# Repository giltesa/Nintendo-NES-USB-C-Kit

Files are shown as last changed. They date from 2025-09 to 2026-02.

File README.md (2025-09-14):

# Nintendo NES USB-C Kit

The **Nintendo NES: USB-C Kit** is a board that allows to replace the original charging connector for a modern and standard **USB-C**.

**If your original connector is too old or damaged** and you need a new one, or **if you would like to power up your Super Nintendo with a standard USB-C charger**, such as the charger for your **Nintendo Switch**, phone, or laptop, you can do so with this kit.

Moreover, with this board, **you can remove the original, old, and inefficient power converter**. Since the console operates at 5V, you only need the power from USB-C and a regular charger.

This board is compatible with this model:

*   Nintendo NES

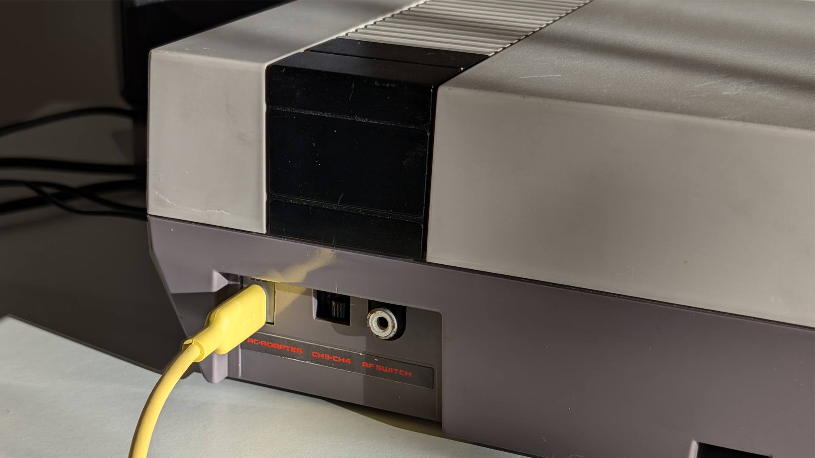
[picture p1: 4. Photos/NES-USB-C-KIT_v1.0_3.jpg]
Nintendo-NES-USB-C


## Would you like it?

https://shop.giltesa.com/product/nintendo-nes-usb-c-kit/

## More

- [giltesa.com](https://giltesa.com "giltesa.com")
- [twitter.com](https://twitter.com/giltesa "twitter.com")

## License

This project is licensed under a **Creative Commons** license:
**[Attribution-NonCommercial-ShareAlike 4.0 International (CC BY-NC-SA 4.0) ](https://creativecommons.org/licenses/by-nc-sa/4.0/)**

Check the [LICENSE.md](LICENSE.md) for more information.

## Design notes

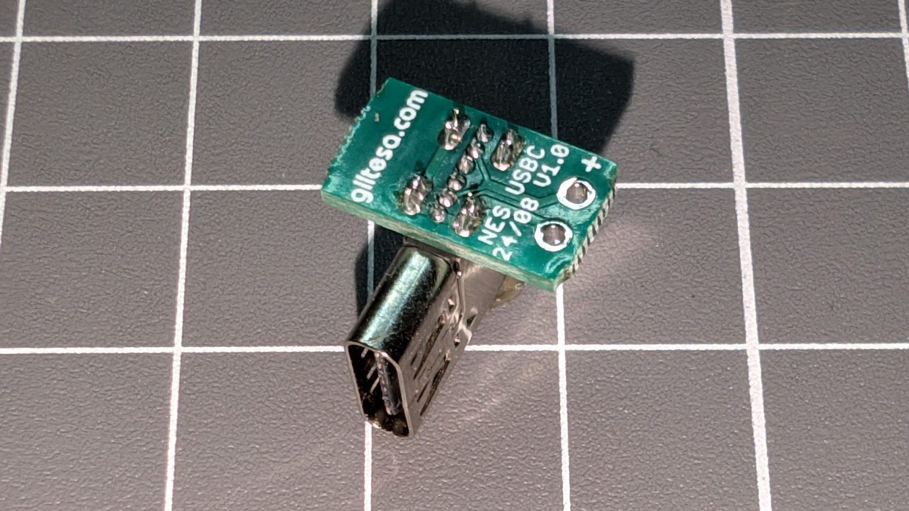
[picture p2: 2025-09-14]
4. Photos/NES-USB-C-KIT_v1.0_1.jpg

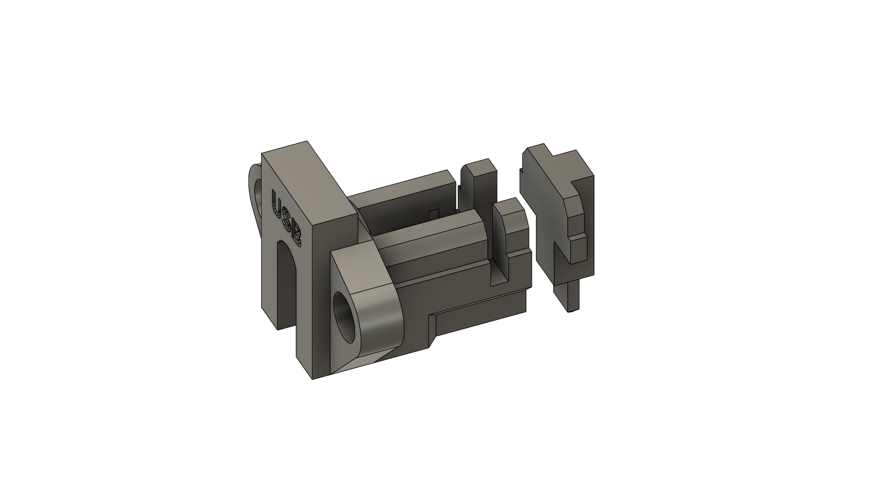
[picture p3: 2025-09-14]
2. Renders, 3D models/Plastic Cap/Nintendo NES Cap v35_2.png

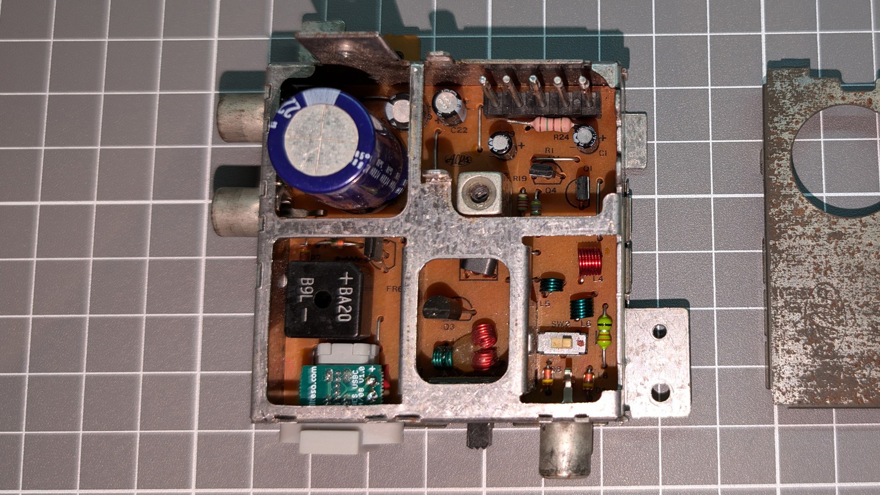
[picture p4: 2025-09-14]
4. Photos/NES-USB-C-KIT_v1.0_2.jpg

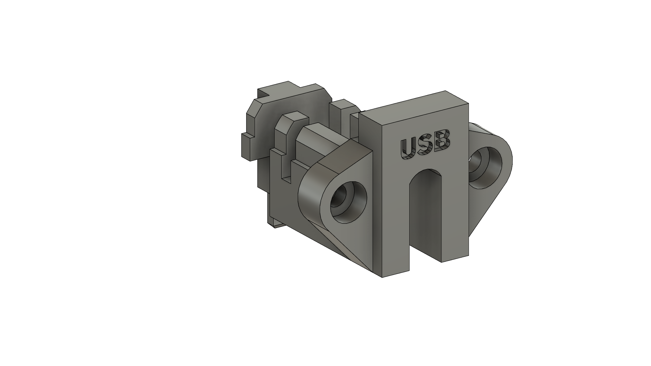
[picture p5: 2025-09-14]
2. Renders, 3D models/Plastic Cap/Nintendo NES Cap v35_1.png

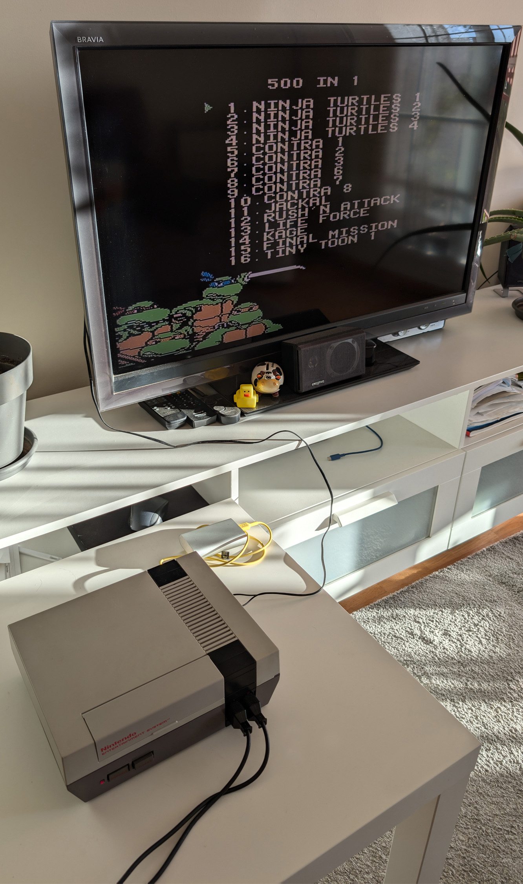
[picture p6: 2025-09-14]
4. Photos/NES-USB-C-KIT_v1.0_4.jpg

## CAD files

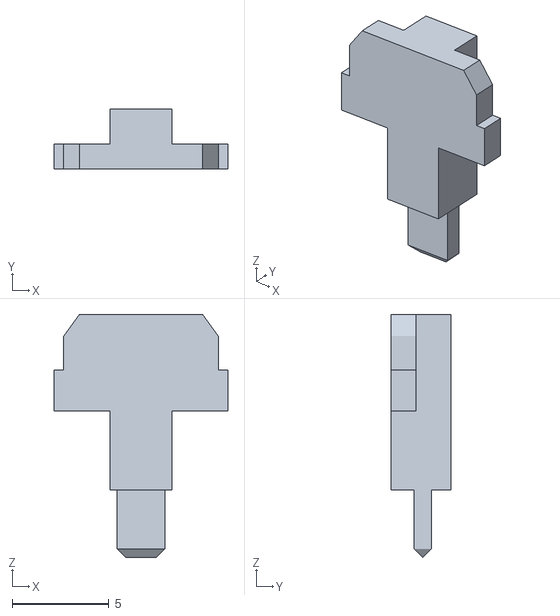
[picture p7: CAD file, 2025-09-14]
2. Renders, 3D models/Plastic Cap/Nintendo NES Cap p2 v35.stl
9.00 x 3.10 x 12.6

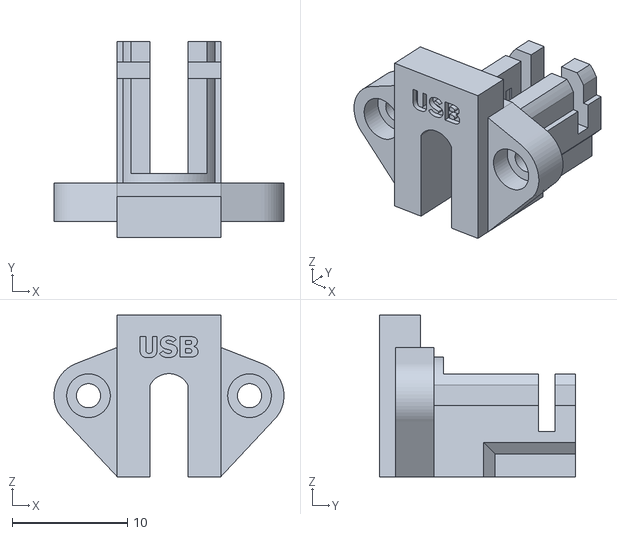
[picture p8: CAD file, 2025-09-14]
2. Renders, 3D models/Plastic Cap/Nintendo NES Cap p1 v35.stl
20.0 x 17.1 x 14.1

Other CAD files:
2. Renders, 3D models/Plastic Cap/Nintendo NES Cap v35.f3d

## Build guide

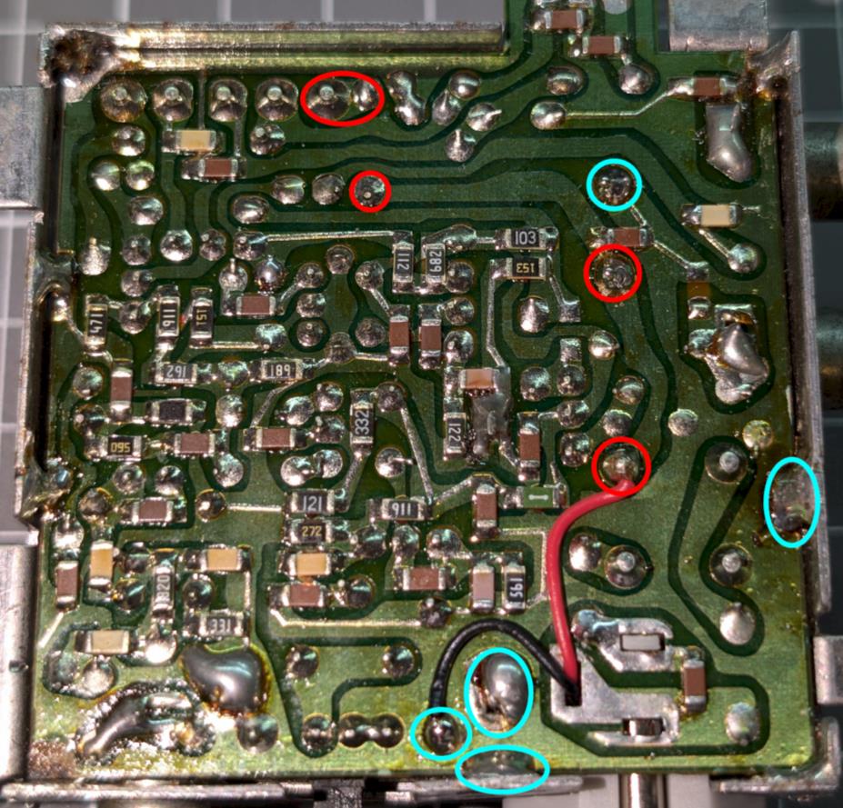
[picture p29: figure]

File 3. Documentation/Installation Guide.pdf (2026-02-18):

# Nintendo NES USB-C Kit

PRODUCT

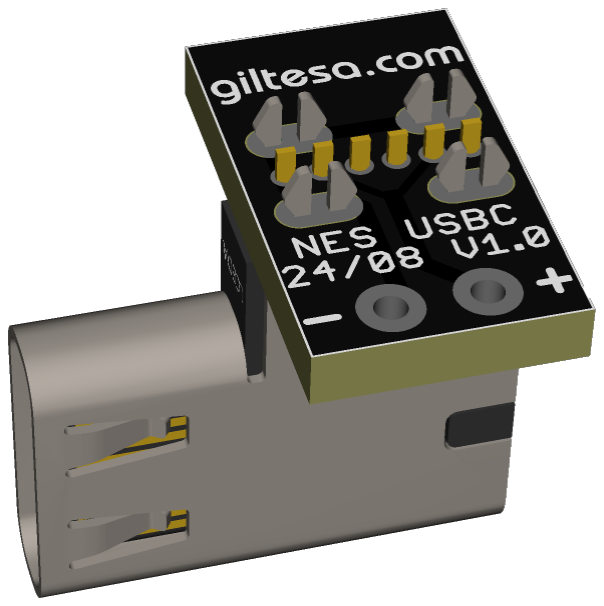
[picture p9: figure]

HTTPS://SHOP.GILTESA.COM/PRODUCT/NINTENDO-NES-USB-C-KIT

# PLEASE READ THROUGH THESE INSTRUCTIONS

ENTIRELY BEFORE ATTEMPTING TO INSTALL.

# WARNING: IF YOU ARE NOT COMFORTABLE WITH SOLDERING, OR PERFORMING ANY STEP IN THIS

GUIDE, DO NOT PERFORM THE INSTALL YOURSELF.

# FIND SOMEONE WHO IS COMFORTABLE TO DO IT FOR

YOU.

INDEX

# Description

The Nintendo NES: USB-C Kit is a board that allows to replace the original power connector for a modern and standard USB-C.

If your original connector is too old or damaged and you need a new one, or if you would like to power up your Nintendo NES with a standard USB-C charger, such as the charger for your Nintendo Switch, phone, or laptop, you can do so with this kit.

Moreover, with this board, you can remove the original, old, and inefficient power converter. Since the console operates at 5V, you only need the power from USB-C and a regular charger.

# FEATURES

- Exact shape for Nintendo NES.
- External power through USB-C.

# INCLUDED

- 1 USB-C board.
- 1 Cable of two wires.
- 1 Plastic cap for the USB-C board.
- 1 Plastic cap retainer.

# Recommended / REQUIRED (NOT INCLUDED)

- Phillips screwdriver.
- Cutting plier.
- Soldering iron / hot-air soldering station.
- Tin.
- Flux.
- Desoldering pump.
- Desoldering mesh.
- Isopropyl alcohol.

# NOTES

This mod disables the video output through the antenna connector, so you will always need to use the AV output.

# Board details

There are 2 pads where the included wires can be soldered. The following explains what each pad is for.

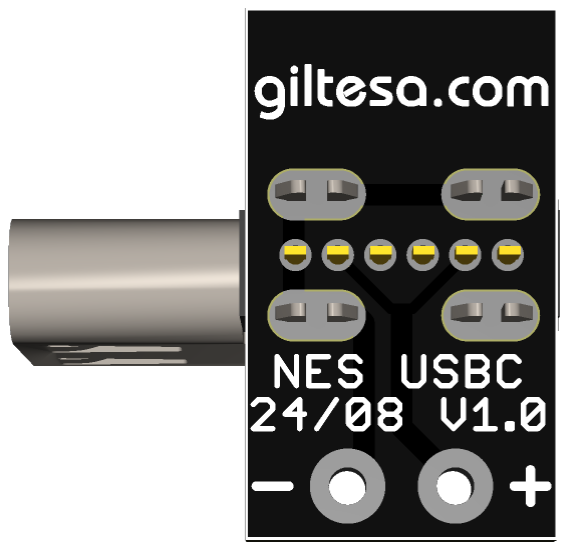
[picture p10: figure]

- + | The +5V line output to power the NES main board.
- - | The ground pad.

# Test the board!

Before starting the installation, you should test the board. If it doesn’t work contact me for a replacement (https://shop.giltesa.com/refund-policy/) (all boards are fully tested, but they may damage during the shipping, we try to package them as better as possible), if it works, go ahead with the installation.

Connect the power from your USB charger to the USB-C connector on the board. Then, with a multimeter in voltage measurement mode, check for a 5V reading. If that's the case, continue with the installation.

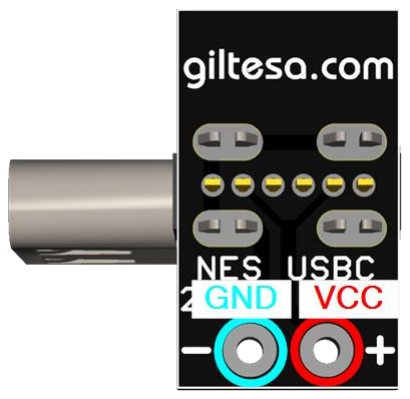
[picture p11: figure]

# INSTALLATION STEPS

Please, carefully read the following steps for a successful installation.

## Pre installation Steps

Before the installation, your NES may need some extra steps to have it ready for the kit.

1. Disassembly the Nintendo NES

Use phillips screwdriver to open the shell and remove the 6 screws.

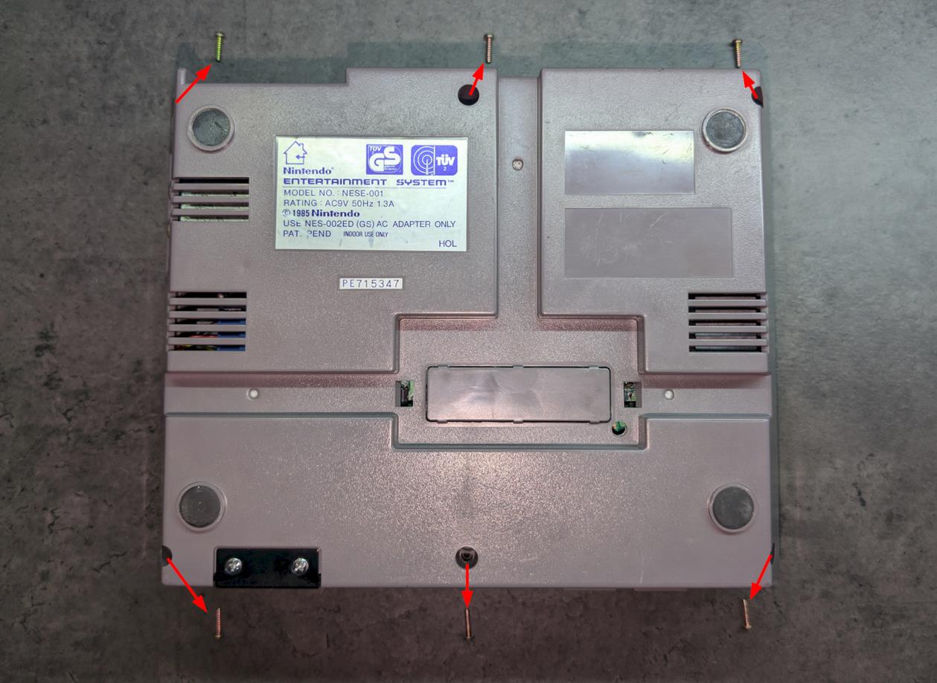
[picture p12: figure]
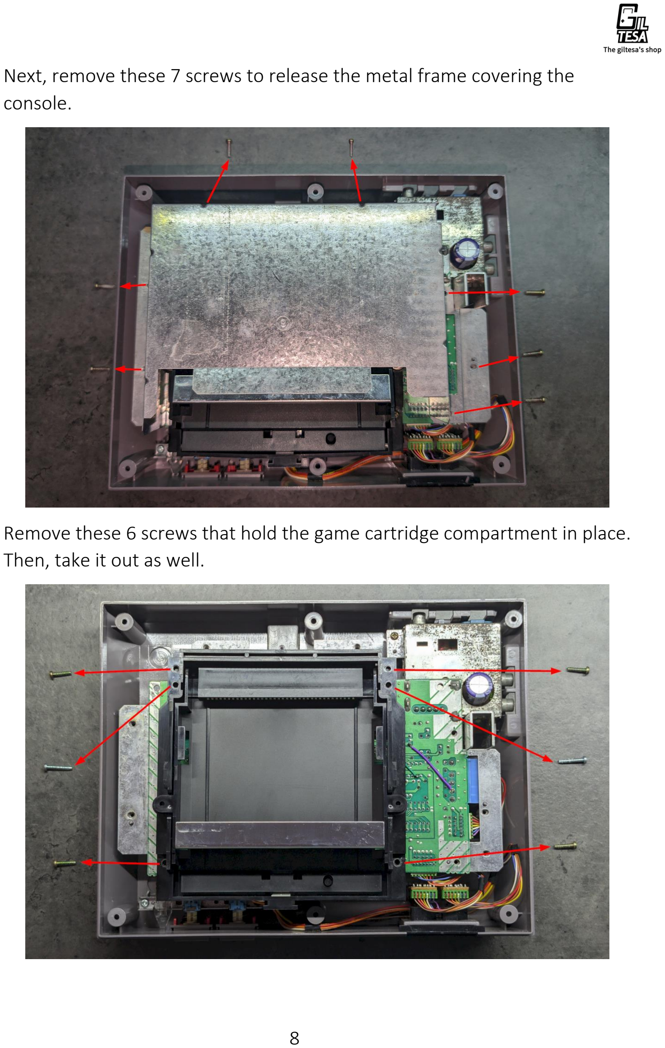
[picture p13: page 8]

Next, remove these 7 screws to release the metal frame covering the console.

Remove these 6 screws that hold the game cartridge compartment in place. Then, take it out as well.

Finally, take out these 2 screws. After that, you can remove the circuit board from the lower shell, but first, disconnect the three cables that connect the circuit board to the shell.

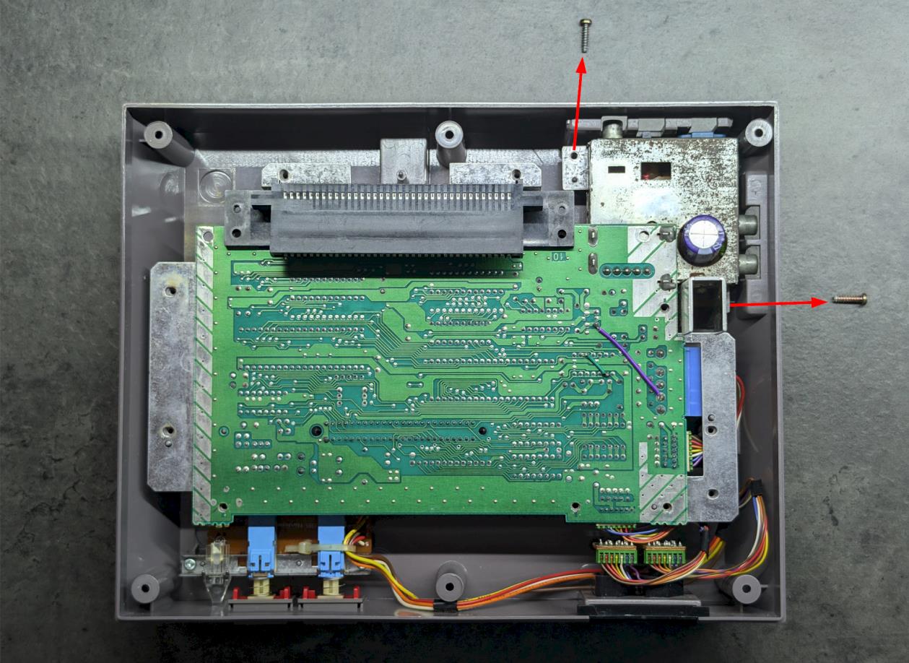
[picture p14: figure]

Now begins the most complex part of the installation. You need to remove the metal box that contains all the power, video, and audio connectors. Inside, you'll find the power connector, which needs to be replaced, along with some small modifications to the circuit.

Desolder all these pads using the soldering iron at maximum power. If you have a hot air soldering station, you can heat the PCB simultaneously to help with the process.

IMPORTANT NOTE: If you use a hot air station, cover the blue capacitor on the right with kapton tape. You should also remove the game connector on the left (it’s not soldered, just slotted in, and can be easily removed and reinserted).

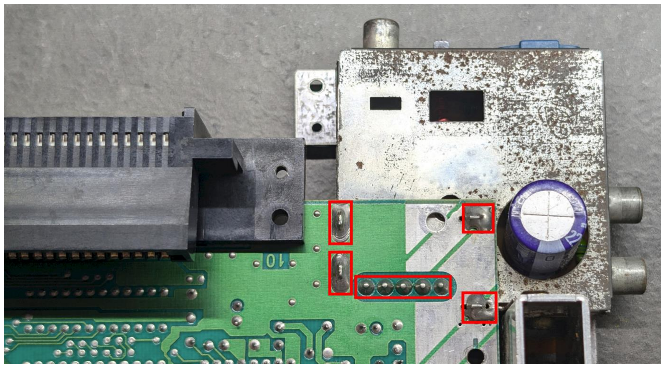
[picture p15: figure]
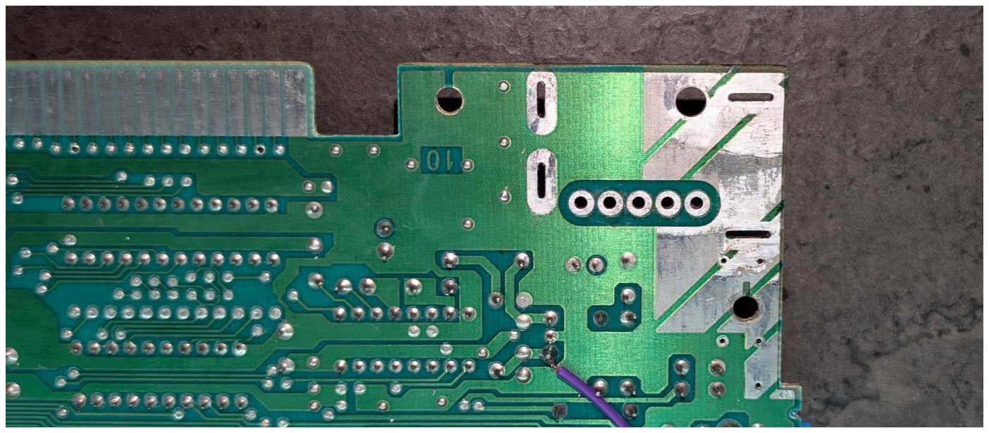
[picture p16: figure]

## installation Steps

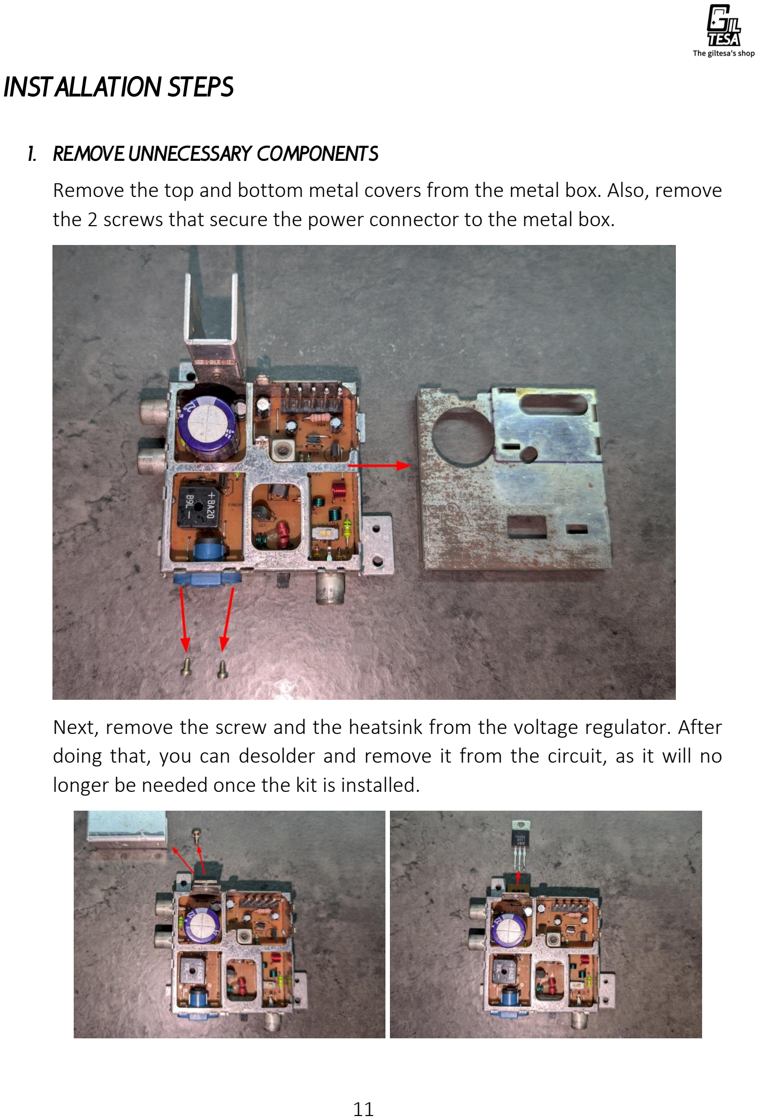
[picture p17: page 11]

1. Remove unnecessary components

Remove the top and bottom metal covers from the metal box. Also, remove the 2 screws that secure the power connector to the metal box.

Next, remove the screw and the heatsink from the voltage regulator. After doing that, you can desolder and remove it from the circuit, as it will no longer be needed once the kit is installed.

It's impossible to remove the power connector without breaking it. This is because the metal shell and the circuit board encase the connector.

The easiest and most recommended way is to destroy the power connector using cutting plier, allowing it to be removed. To do this:

- First, desolder the connector, trying to remove as much solder as possible from its 3 pads.
- Then, use cutting plier to cut it into pieces until it is completely removed.
- Finally, make sure the pads where the connector was soldered are completely free of solder, with the holes fully clear. This is necessary for later steps.

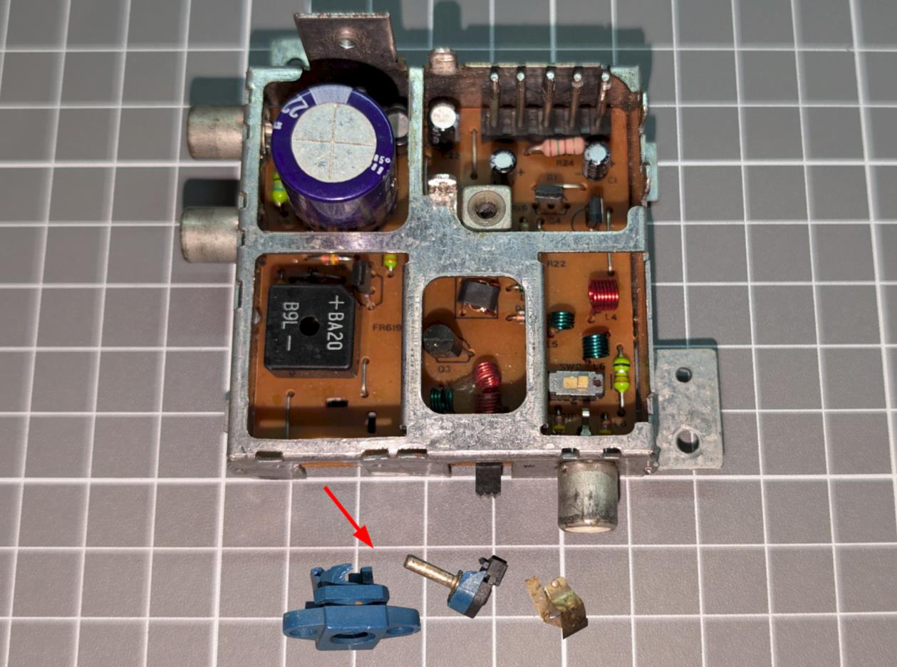
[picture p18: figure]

2. Cable installation

Solder the included wires onto the pads of the USB-C board. Solder the red wire to the pad marked with a +, and the black wire to the pad marked with a –

Clean the circuit with alcohol once you finish soldering the wires.

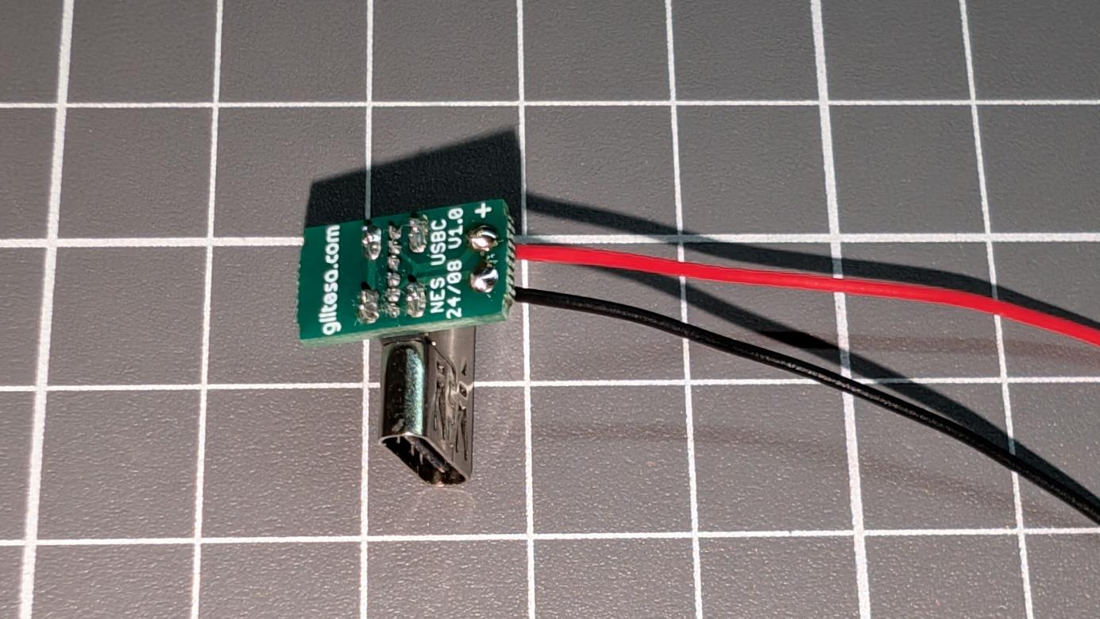
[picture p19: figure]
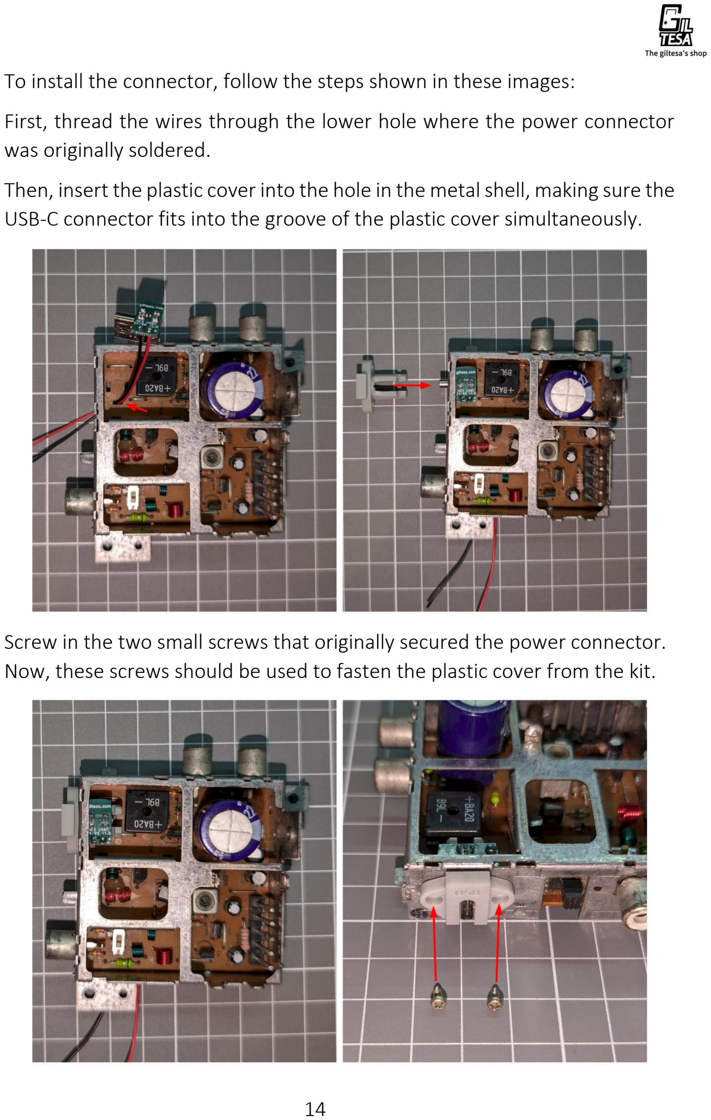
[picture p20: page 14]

To install the connector, follow the steps shown in these images:

First, thread the wires through the lower hole where the power connector was originally soldered.

Then, insert the plastic cover into the hole in the metal shell, making sure the USB-C connector fits into the groove of the plastic cover simultaneously.

Screw in the two small screws that originally secured the power connector. Now, these screws should be used to fasten the plastic cover from the kit.

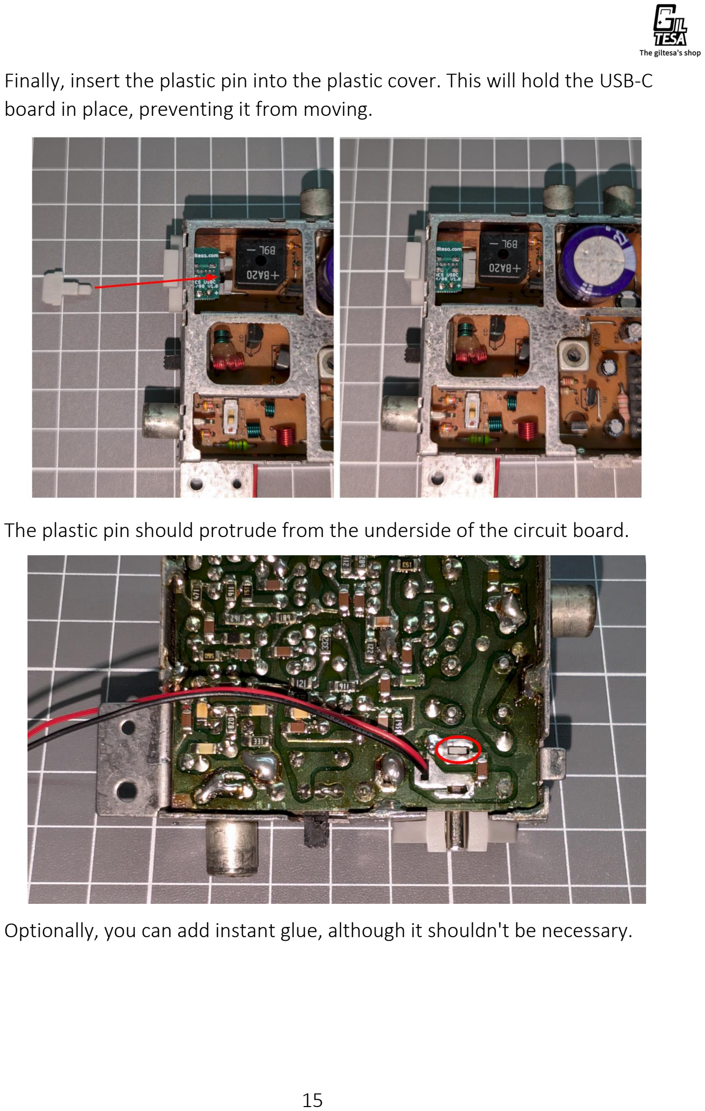
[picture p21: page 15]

Finally, insert the plastic pin into the plastic cover. This will hold the USB-C board in place, preventing it from moving.

The plastic pin should protrude from the underside of the circuit board.

Optionally, you can add instant glue, although it shouldn't be necessary.

Solder the wires onto these two pads, making sure they are cut to the correct length beforehand.

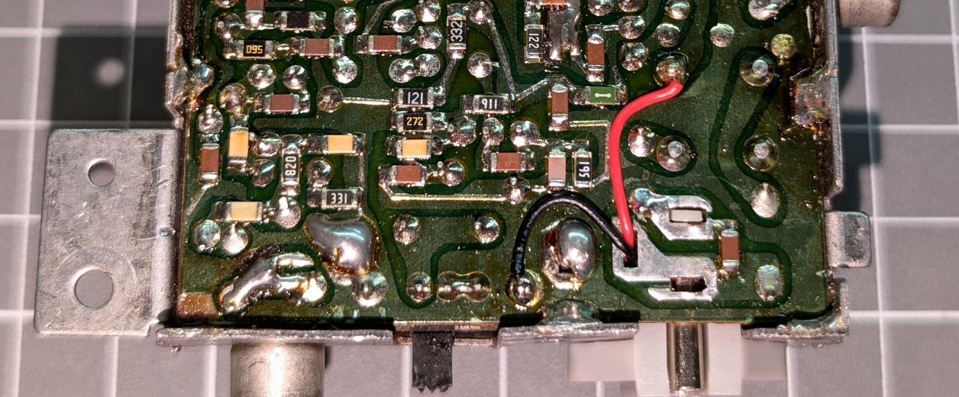
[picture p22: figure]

Since there are different versions of the circuit and the pads may be slightly repositioned, you can ensure that you are soldering each wire to the correct location by using a multimeter.

The black wire (GND) should be soldered to the pad shown in the photo, which is connected to the GND plane of the circuit and the metal shell covering it.

The red wire should be connected to the positive pad of the large capacitor, as well as to the power output pin.

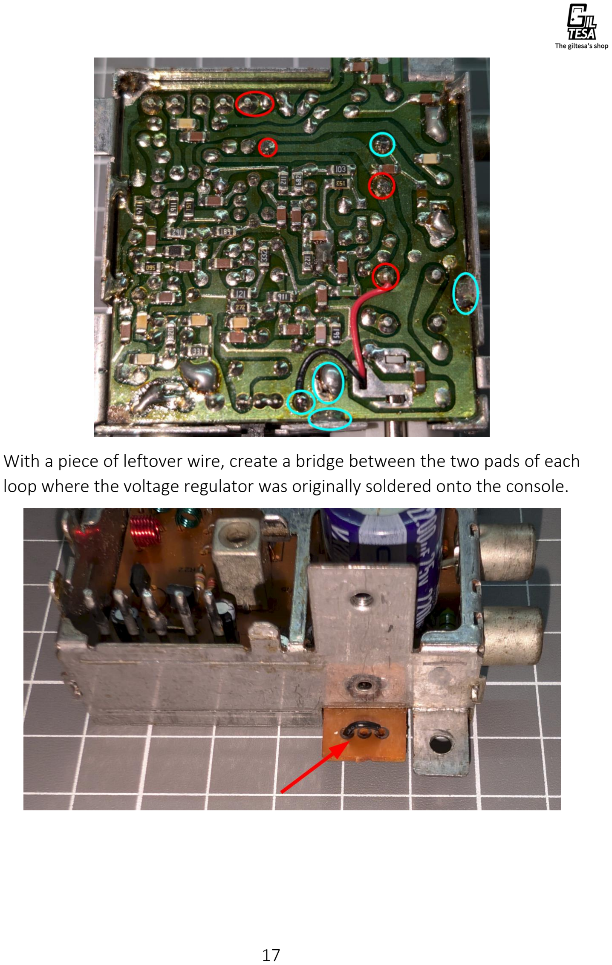
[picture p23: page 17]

With a piece of leftover wire, create a bridge between the two pads of each loop where the voltage regulator was originally soldered onto the console.

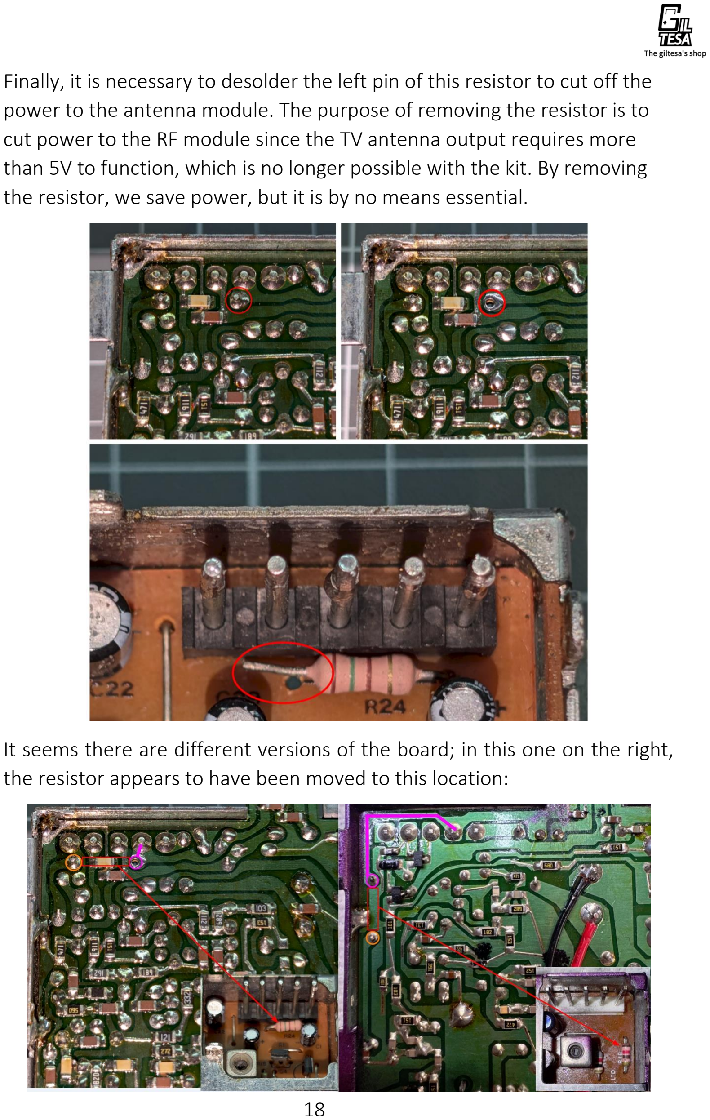
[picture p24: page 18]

Finally, it is necessary to desolder the left pin of this resistor to cut off the power to the antenna module. The purpose of removing the resistor is to cut power to the RF module since the TV antenna output requires more than 5V to function, which is no longer possible with the kit. By removing the resistor, we save power, but it is by no means essential.

It seems there are different versions of the board; in this one on the right, the resistor appears to have been moved to this location:

3. Done!

Follow the steps backward, placing each thing in its place, and the installation will be complete!

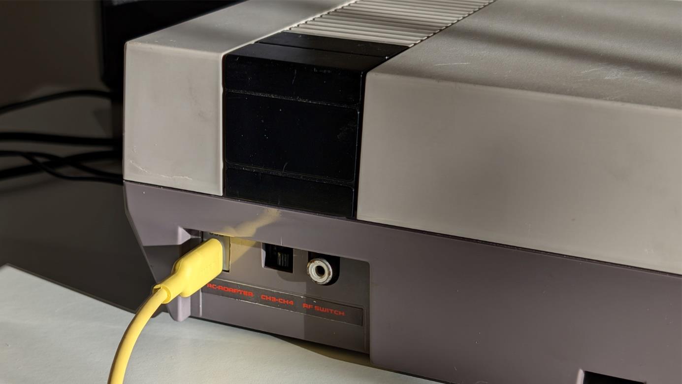
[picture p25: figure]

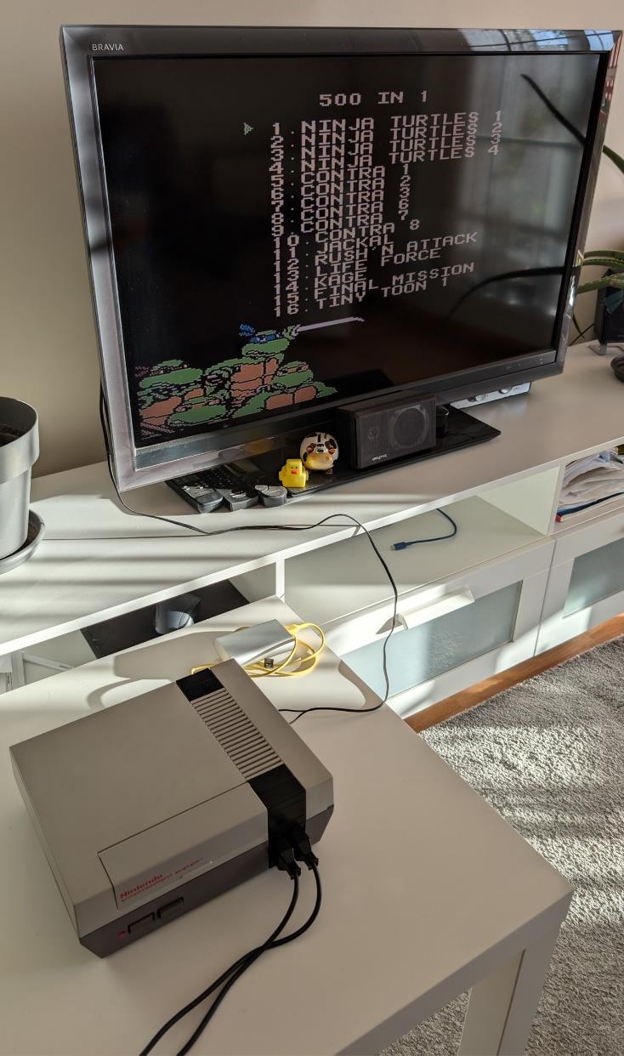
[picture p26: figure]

# Frequently Asked Questions - FAQ

What charger can be used?
You can use any standard charger for mobile phones, computers, etc., with 5V 1A. It doesn't need to be a Power Delivery charger since this feature is not used. Of course, if you want to use a Power Delivery charger, there's no problem or risk.

Technical data for curious minds:

Power Delivery chargers can supply a wide range of voltages: 5V, 9V, 12V, 15V, and 20V. However, for this to happen, the device must communicate with the charger to explicitly request the desired voltage. Without this communication, the charger will never supply more than 5V. That's one of the advantages of USB-C, as it can be used with both old and modern devices.

My console doesn’t turn on
- Make sure you have connected all the cables from the casing (buttons and game ports) to the connectors on the mainboard.
- Check that you have made the bridge where the console's voltage regulator was originally soldered. Also, check with a multimeter that there is continuity between both ends.

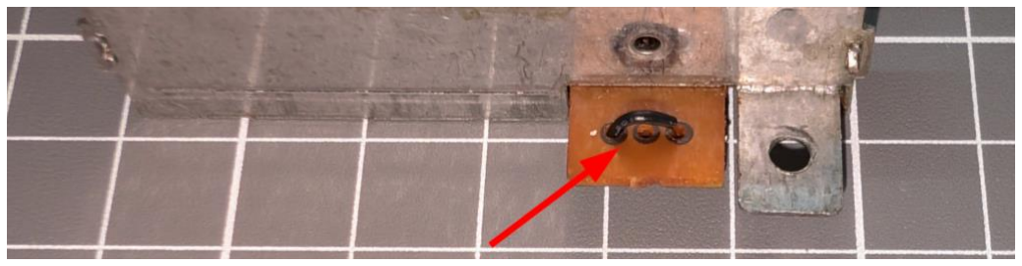
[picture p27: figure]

- If that's not the issue, use a multimeter to check that you have 5V on the 5V OUT pin of the RF module. (With the USB-C connected)

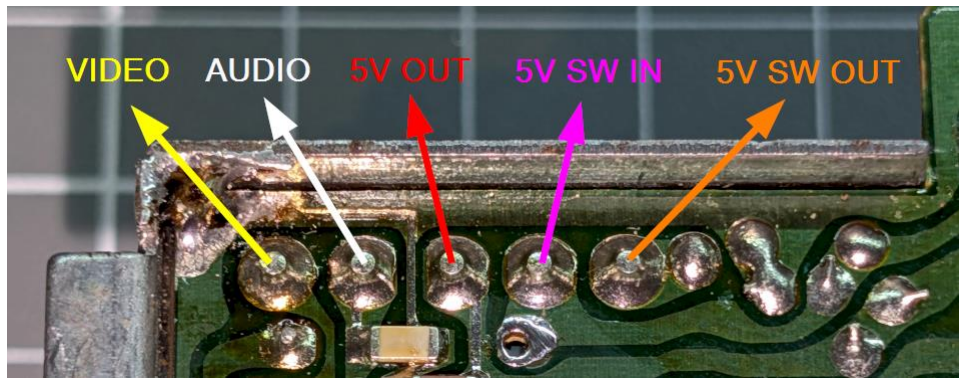
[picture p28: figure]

- If the problem persists, check for continuity between the 5V SW IN and 5V SW OUT pins when you set the console's power switch to the ON position. (With the USB-C disconnected)
- Check that there is continuity between these points for each color corresponding to VCC and GND. (Image in larger size on previous pages)
